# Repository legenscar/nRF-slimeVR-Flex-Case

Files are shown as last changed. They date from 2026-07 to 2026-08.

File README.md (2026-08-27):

# FlexCase -  nRF SlimeVR 
FlexCase is a 3D printable case design for stacked ProMicro nrf52840 based SlimeVR trackers that utilizing Heat-set inserts for increased repairability. At only 8x36x70mm and with a flexible TPU bridge, you should only feel the straps! (ignore the bad handwriting please)

3 trackers

In addition, space is provided under the ProMicro as well to allow soldering from under the ProMicro. I advise you to read through the whole README before starting. 

## What you will need
### tools:
- Soldering iron
- solder
- wire cutter / scissors
- solder flux (optional)
- heat-set insert tip for your soldering iron
- Kapton tape
- access to a 3D printer or 3D printing service
- multimeter (optional)
- tweezers (optional)
### per tracker:
- 4x 5x4xM3 (length x outer diameter x inner diameter) brass heat inserts
- 4x 6mm M3 Flathead screws
- 5x 3D printed parts
- 1x 3.7V Lipo battery (smaller than 5x17x31mm) with wires longer than 60mm
- 1x ProMicro nRF52840
- 1x IMU of your choice
- 1x 2-pin button
- Wire (31.2mm)
- Hook side Velcro

## Assembly
### Soldering 
Refer to the official SlimeVR docs (https://docs.slimevr.dev/smol-slimes/hardware/smol-tracker.html) for soldering your ProMicros. Beware that for your ProMicros to fit this case, the IMU Breakout board + ProMicro together should not exceed 5mm in height. There should also be enough space for the antennae wire to be routed next to the IMU as shown in the pictures.

Note: Be careful not to short the components near the buttons if the button housing is made of metal. 

### Printing
For each tracker you will need 5 printed parts. The parts for the cases (4 per tracker) are to be printed with a hard material (PLA, PETG etc.) while the TPU bridge should, as the name suggests, be printed with a flexible material (TPU 95A, 68D etc.). While printing, make sure to enable supports. 

### Assembling
First, insert the heat inserts into the case, 2 on each side of one tracker (left one is for the battery, right one for the ProMicro).

Cases

Now its time to solder the battery to the ProMicros. Cut the red wire to 60mm and the black wire to 55mm. Pull the wires through the little opening in the TPU bridge and solder them to the ProMicro. Keep the TPU bridge away while doing so to avoid damage. 

Now you can fit everything into the case! While closing the case, make sure not to pinch any wires. Tweezers will be very useful here! Screw everything together and youre done!

internal
finished tracker

Cut 2 pieces of Velcro and tape them to the back. Your trackers are now ready to use!

tracker back

## Notes
- Depending on your printer and filament some sanding is required. 
- Ive designed the cases so that the ProMicro clicks in and should not move on its own, however if you want to make sure it stays you can use some double sided tape
- Special thanks to the SlimeVR team for making this possible and @itsJensin for the inspiration!

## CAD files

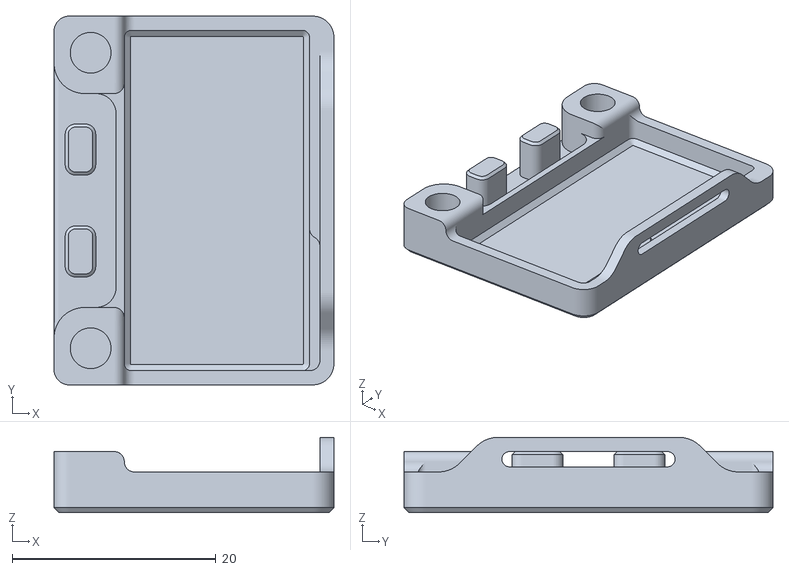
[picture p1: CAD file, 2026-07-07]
STL Files/Battery Housing v6.stl
27.5 x 36.2 x 7.40

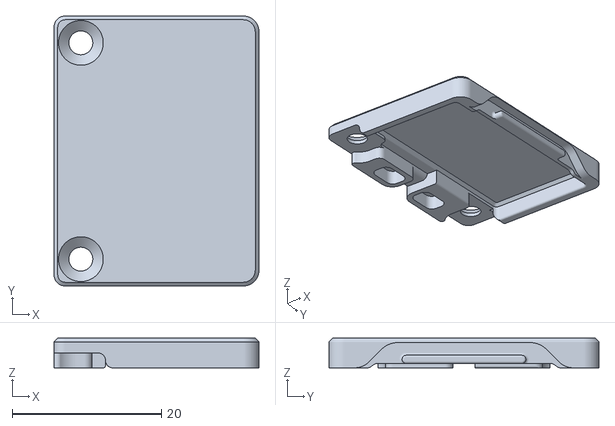
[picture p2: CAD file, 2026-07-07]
STL Files/Battery lid v6.stl
27.5 x 36.2 x 4.00

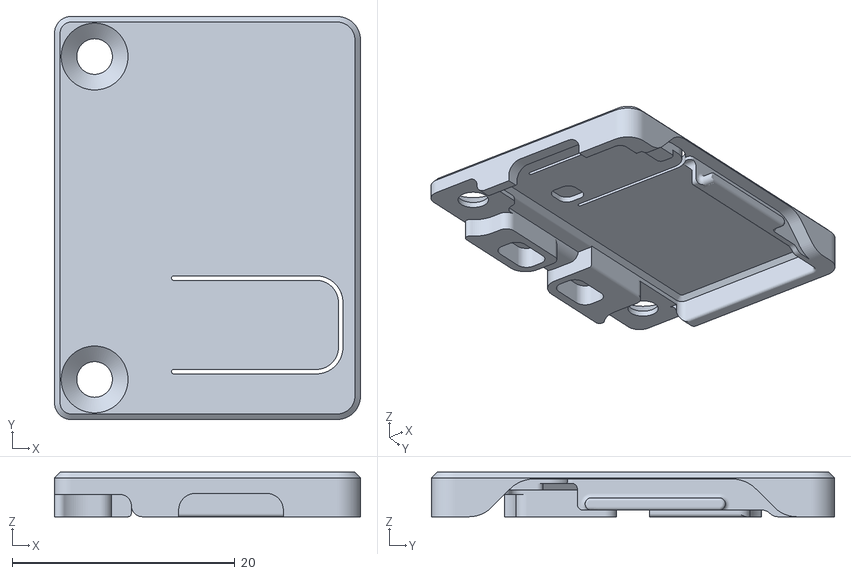
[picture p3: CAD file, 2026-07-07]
STL Files/PCB lid v7.stl
27.5 x 36.2 x 4.00

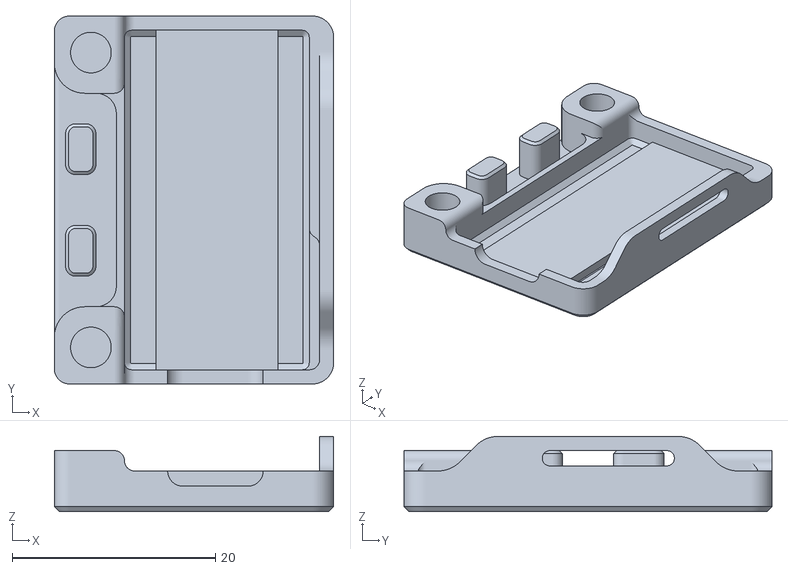
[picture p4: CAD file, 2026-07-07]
STL Files/PCB Housing v6.stl
27.5 x 36.2 x 7.40

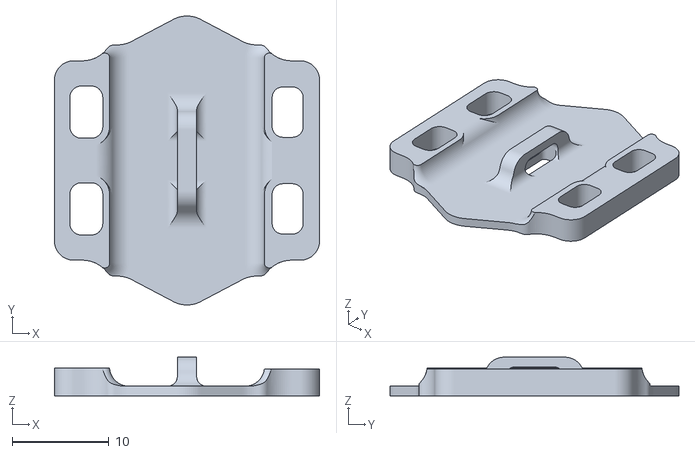
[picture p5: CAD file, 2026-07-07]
STL Files/Bridge v3.stl
27.4 x 29.9 x 4.00

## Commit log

2026-07-06 Revise README for Flex Case assembly instructions
    Updated the README to provide detailed instructions for assembling the Flex Case for nRF SlimeVR trackers, including tools needed, assembly steps, and printing guidelines.
2026-07-06 Fix formatting and title case in README.md
2026-07-06 Revise README for improved clarity and instructions
    Updated README.md for clarity and added details about assembly and components.
2026-07-07 Revise FlexCase dimensions and assembly instructions
    Updated dimensions for the FlexCase design and added notes on antennae wire routing during assembly.
2026-07-07 Update README with detailed assembly instructions
    Clarified assembly instructions and added final steps for tracker preparation.
2026-07-07 Rename Battery Base v6.stl to Battery Housing v6.stl
    [Battery Housing v6.stl]
2026-07-07 Rename PCB housing v6.stl to PCB Housing v6.stl
    [PCB Housing v6.stl]
2026-07-07 Clarify TPU material specifications in README
    Updated the TPU material specification from 'TPU 95A etc.' to 'TPU 95A, 68D etc.' for clarity.
2026-07-24 Revise battery specifications in README
    Updated battery dimensions in README and removed mention of battery capacity.
